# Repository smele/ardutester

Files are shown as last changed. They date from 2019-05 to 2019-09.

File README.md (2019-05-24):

# ardutester

#Work in progress...

An ATmega328 µC Component Tester based on work of ArduTester ver. 0.7f 

 Original Source from:        http://www.mikrocontroller.net/articles/AVR-Transistortester
 Original Software:           by Karl-Heinz Kuebbeler (kh_kuebbeler@web.de)
                              The Ardutester software is based on porting by Markus Reschke (madires@theca-tabellaria.de) 
 
 Schematic & Home Page:       
 
 Arduino version:             PighiXXX
                              PaoloP 
 
 - ONLY TTL COMPONENTS!

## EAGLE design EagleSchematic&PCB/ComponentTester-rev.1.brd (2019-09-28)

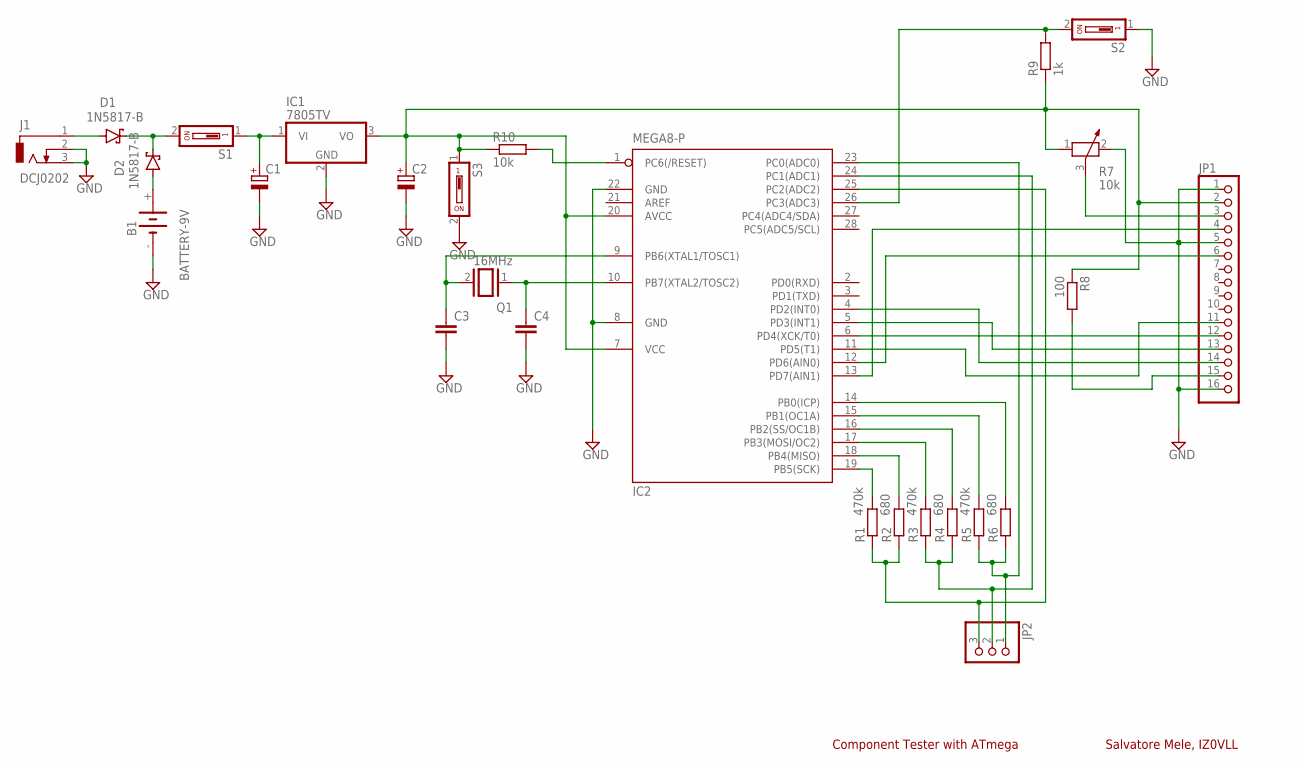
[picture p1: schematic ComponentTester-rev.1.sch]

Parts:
B1: BATTERY-9V; 9V-BATTERY-SNAP
C1, C2: CPOL-EUE2.5-6; E2,5-6
C3, C4: C-EU025-024X044; C025-024X044
D1, D2: 1N5817-B; DO41-7.6
IC1: 7805TV; TO220V
IC2: MEGA8-P; DIL28-3
J1: DCJ0202
JP1: PINHD-1X16; 1X16
JP2: PINHD-1X3; 1X03
Q1: 16MHz; QS
R1, R3, R5: 470k; 0207/10
R2, R4, R6: 680; 0207/10
R7: 10k; PT-10S
R8: 100; 0207/10
R9: 1k; 0207/10
R10: 10k; 0207/10
S1, S2, S3: SD4-01

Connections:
GND: B1.-, C1.-, C2.-, C3.2, C4.2, IC1.2 (GND), IC2.8 (GND), IC2.22 (GND), J1.2, J1.3, JP1.1, JP1.5, JP1.16, R7.2, S2.1, S3.2
unnamed: C1.+, IC1.1 (VI), S1.1
unnamed: C2.+, IC1.3 (VO), IC2.7 (VCC), IC2.20 (AVCC), JP1.2, R7.1, R8.1, R9.1, R10.1, S3.1
unnamed: IC2.14 (PB0(ICP)), R6.2
unnamed: IC2.15 (PB1(OC1A)), R5.2
unnamed: IC2.16 (PB2(SS/OC1B)), R4.2
unnamed: IC2.17 (PB3(MOSI/OC2)), R3.2
unnamed: IC2.18 (PB4(MISO)), R2.2
unnamed: IC2.19 (PB5(SCK)), R1.2
unnamed: IC2.25 (PC2(ADC2)), JP2.3, R1.1, R2.1
unnamed: IC2.24 (PC1(ADC1)), JP2.2, R3.1, R4.1
unnamed: IC2.23 (PC0(ADC0)), JP2.1, R5.1, R6.1
unnamed: JP1.3, R7.3
unnamed: IC2.26 (PC3(ADC3)), R9.2, S2.2
unnamed: IC2.13 (PD7(AIN1)), JP1.4
unnamed: IC2.12 (PD6(AIN0)), JP1.6
unnamed: IC2.4 (PD2(INT0)), JP1.14
unnamed: IC2.5 (PD3(INT1)), JP1.13
unnamed: IC2.6 (PD4(XCK/T0)), JP1.12
unnamed: IC2.11 (PD5(T1)), JP1.11
unnamed: JP1.15, R8.2
unnamed: C4.1, IC2.10 (PB7(XTAL2/TOSC2)), Q1.1
unnamed: C3.1, IC2.9 (PB6(XTAL1/TOSC1)), Q1.2
unnamed: IC2.1 (PC6(/RESET)), R10.2
unnamed: D1.A, J1.1
unnamed: B1.+, D2.A
unnamed: D1.C, D2.C, S1.2

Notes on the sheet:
Component Tester with ATmega
Salvatore Mele, IZ0VLL

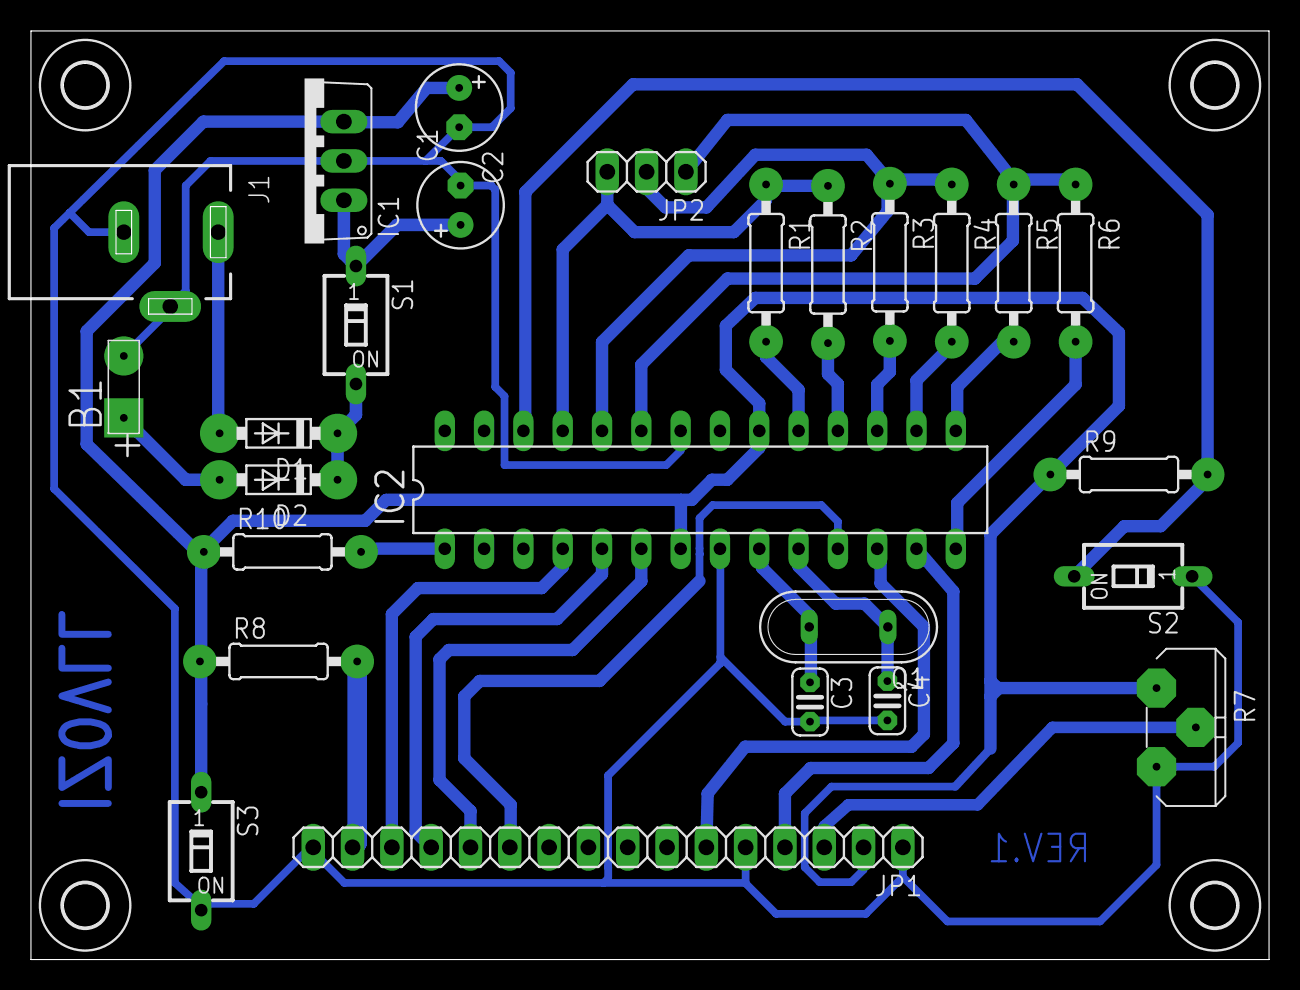
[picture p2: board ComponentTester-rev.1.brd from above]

Board: 2 copper layers, 80.0 x 60.0 mm, 30 parts (0 on the bottom side), 27 nets.

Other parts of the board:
U$1, U$2, U$3, U$4: 2,8

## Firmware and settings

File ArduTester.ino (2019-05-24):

/*

      ___           ___          _____          ___                       ___           ___                       ___           ___     
     /  /\         /  /\        /  /::\        /__/\          ___        /  /\         /  /\          ___        /  /\         /  /\    
    /  /::\       /  /::\      /  /:/\:\       \  \:\        /  /\      /  /:/_       /  /:/_        /  /\      /  /:/_       /  /::\   
   /  /:/\:\     /  /:/\:\    /  /:/  \:\       \  \:\      /  /:/     /  /:/ /\     /  /:/ /\      /  /:/     /  /:/ /\     /  /:/\:\  
  /  /:/~/::\   /  /:/~/:/   /__/:/ \__\:|  ___  \  \:\    /  /:/     /  /:/ /:/_   /  /:/ /::\    /  /:/     /  /:/ /:/_   /  /:/~/:/  
 /__/:/ /:/\:\ /__/:/ /:/___ \  \:\ /  /:/ /__/\  \__\:\  /  /::\    /__/:/ /:/ /\ /__/:/ /:/\:\  /  /::\    /__/:/ /:/ /\ /__/:/ /:/___
 \  \:\/:/__\/ \  \:\/:::::/  \  \:\  /:/  \  \:\ /  /:/ /__/:/\:\   \  \:\/:/ /:/ \  \:\/:/~/:/ /__/:/\:\   \  \:\/:/ /:/ \  \:\/:::::/
  \  \::/       \  \::/~~~~    \  \:\/:/    \  \:\  /:/  \__\/  \:\   \  \::/ /:/   \  \::/ /:/  \__\/  \:\   \  \::/ /:/   \  \::/~~~~ 
   \  \:\        \  \:\         \  \::/      \  \:\/:/        \  \:\   \  \:\/:/     \__\/ /:/        \  \:\   \  \:\/:/     \  \:\     
    \  \:\        \  \:\         \__\/        \  \::/          \__\/    \  \::/        /__/:/          \__\/    \  \::/       \  \:\    
     \__\/         \__\/                       \__\/                     \__\/         \__\/                     \__\/         \__\/    
		



 ARDUTESTER v0.X 25/04/2013
 
 Original Source from:        http://www.mikrocontroller.net/articles/AVR-Transistortester
 Original Software:           by Karl-Heinz Kuebbeler (kh_kuebbeler@web.de)
                              The Ardutester software is based on porting by Markus Reschke (madires@theca-tabellaria.de) 
 
 Schematic & Home Page:       http://www.pighixxx.com/lavori/ardutester/ 
 
 Arduino version:             PighiXXX (info@pighixxx.com)
                              PaoloP (http://www.arduino.cc/forum/index.php?action=profile;u=58300)
 
 - ONLY TTL COMPONENTS!
 
 TODO:
 - Detailed Component Analysis
 
 CHANGELOG:
 - 01/05/2013 v06e - Waitus Function, String to Flash Functions, Killed 3 Goto :-), Code Cleanup - PighiXXX 
 - 01/05/2013 v06f - Killed all Goto (Thanks to PaoloP), Implemented Button
 - 01/05/2013 v06g - Code Cleanup
 - 02/05/2013 v06h - Code Cleanup, SERIAL-LCD Flag, I2C LCD Functions
 - 02/05/2013 v06i - Button Flag, Button Function
 - 02/05/2013 v06j - PowerSave Function, Code Cleanup, Flag only when more info
 - 02/05/2013 v06k - Some fix (By PaoloP)
 - 03/05/2013 v06l - Disabled digital input on analog pins (By PaoloP), Minor fixes
 - 04/05/2013 v06m - ShowFET() fixed, Code Cleanup, Short Circuit Ok
 - 05/05/2013 v06n - CheckResistor Function Ok
 - 06/05/2013 v06o - SelfTest Function (v0.3), SelfAdjust, Minor fixes
 - 21/05/2013 v06p - Add LCD no I2C, Removed Leonardo support: this sketch work only on ATmega328. (By PaoloP)
 - 07/06/2013 v06q - ArduTester Software Client Functions (By PighiXXX)
 - 08/07/2013 v07a - SmallResistor() fixes, Inductance Measurement, Leakage Current Measurement, BJT functions fixed, Minor fixes (By PighiXXX)
                     TODO ReCheck Print Functions & LCD Functions - This is an alpha version! Lightless version!
 - 17/07/2013 v07b - MOSFETs function fixed, Minor fixes, Show Functions revisited, I2C LCD Deprecated, Deep debug :-)
                     Button Function revisited, PWM Tool, Serial Menu, AutoAdjust, EEProm functions (By PighiXXX)
 - 21/07/2013 v07c   Some fix (By PaoloP), LCD Functions revisited (By PighiXXX) 
 - 22/07/2013 v07d   LCDMenu, Some fix (By PighiXXX)
 - 23/07/2013 v07e   SetDefault function, Some fix, selFreq optimized, TestKey improvements, Client support (By PighiXXX)
                     TWI, SPI, TIMER2 disabled (By PaoloP)
 - 25/07/2013 v07f   ReadU function revisited (By PaoloP), Some fix (By PaoloP & PighiXXX)

*/

//WorkAround for IDE ifndef bug
char foo; 

                                                 //ARDUTESTER FEATURES

//Remember LCD_PRINT or DEBUG_PRINT
#define BUTTON_INST                              //Button Installed
#define LCD_PRINT                                //Print on LCD
//Remember DEBUG_PRINT or ATSW
//#define ATSW                                   //ArduTester Software Client Enabled
#define DEBUG_PRINT                            //Print on Serial Port
#define DET_COMP_ANALYSIS                        //Detailed Component Analysis (Soon)
#define TIMEOUT_BL            600                //LCD Backlight Timeout
#define LONG_PRESS            26                 //Button Long Press
#define USER_WAIT             3000               //Nexpage Timeout

//Check features
#if not defined(__AVR_ATmega328P__)
    #error Sorry, this program works only on Arduino Uno 
#endif
#if defined(LCD_PRINT) && defined(DEBUG_PRINT)
  #error Invalid Parameters: Use LCD_PRINT or DEBUG_PRINT
#endif

#if defined(DEBUG_PRINT) && defined(ATSW)
  #error Invalid Parameters: Use DEBUG_PRINT or ATSW
#endif

//Includes
#include <avr/wdt.h>
#include <avr/sleep.h>
#include <avr/power.h>
#include <EEPROM.h>

//LCD Output
#ifdef LCD_PRINT
  #include <LiquidCrystal.h>
  LiquidCrystal lcd(7, 6, 5, 4, 3, 2);           //RS,E,D4,D5,D6,D7
#endif

//UINT32_MAX
#define UINT32_MAX            ((uint32_t)-1)

//Test probes - Must be an ADC port :-)
#define ADC_PORT              PORTC              //ADC port data register 
#define ADC_DDR               DDRC               //ADC port data direction register 
#define ADC_PIN               PINC               //Port input pins register 
#define TP1                   0                  //Test pin 1 (=0) 
#define TP2                   1                  //Test pin 2 (=1) 
#define TP3                   2                  //Test pin 3 (=2) 
/*
   Probe resistors: 
   The resistors must be connected to the lower 6 pins of the port in
   following sequence:
    - pin 0: Rl1 680R (test pin 1)
    - pin 1: Rh1 470k (test pin 1)
    - pin 2: Rl2 680R (test pin 2)
    - pin 3: Rh2 470k (test pin 2)
    - pin 4: Rl3 680R (test pin 3)
    - pin 5: Rh3 470k (test pin 3)
*/
#define R_PORT                PORTB              //Port data register 
#define R_DDR                 DDRB               //Port data direction register

//Push button
#define TEST_BUTTON           A3                 //Test/start push button (low active)

//Button Delay
#define CYCLE_DELAY           3000

                                                 //ARDUESTER PARAMETERS

//Maximum number of measurements without any components found.
#define CYCLE_MAX             5
//ADC voltage reference based on Vcc (in mV). 
#define UREF_VCC              5001
/*
  Offset for the internal bandgap voltage reference (in mV): -100 up to 100
   - To compensate any difference between real value and measured value.
   - The ADC has a resolution of about 4.88mV for V_ref = 5V (Vcc) and
     1.07mV for V_ref = 1.1V (bandgap).
   - Will be added to measured voltage of bandgap reference.
*/
#define UREF_OFFSET           0
/*
   Exact values of probe resistors.
    - Standard value for Rl is 680 Ohms.
    - Standard value for Rh is 470k Ohms.
*/
//Rl in Ohms
#define R_LOW                 680
//Rh in Ohms
#define R_HIGH                470000
//Offset for systematic error of resistor measurement with Rh (470k) in Ohms.
#define RH_OFFSET             700 
/*
   Resistance of probe leads (in 0.01 Ohms).
    - Resistance of two probe leads in series.
    - Assuming all probe leads got same/similar resistance.
*/
#define R_ZERO                20
/* 
   Capacitance of the wires between PCB and terminals (in pF).
   Examples:
    - 2pF for wires 10cm long
*/
#define CAP_WIRES             15
/* 
   Capacitance of the probe leads connected to the tester (in pF).
   Examples:
     capacity  length of probe leads
     -------------------------------
      3pF      about 10cm
      9pF      about 30cm
     15pF      about 50cm
*/
#define CAP_PROBELEADS        9
//Maximum voltage at which we consider a capacitor being discharged (in mV)
#define CAP_DISCHARGED        2
/*
   Number of ADC samples to perform for each mesurement.
    - Valid values are in the range of 1 - 255.
*/
#define ADC_SAMPLES           25
//Estimated internal resistance of port to GND (in 0.1 Ohms)
#define R_MCU_LOW             200                //Default: 209
//Estimated internal resistance of port to VCC (in 0.1 Ohms)
#define R_MCU_HIGH            220                //Default: 235
//Voltage offset of ÂµCs analog comparator (in mV): -50 up to 50
#define COMPARATOR_OFFSET     15
//Capacitance of the probe tracks of the PCB and the ÂµC (in pF)
#define CAP_PCB               42
//Total default capacitance (in pF): max. 255
#define C_ZERO                CAP_PCB + CAP_WIRES + CAP_PROBELEADS
//ATMEGA328, 16Mhz Related
#define ADC_CLOCK_DIV         (1 << ADPS2) | (1 << ADPS1) | (1 << ADPS0)
#define CPU_FREQ              F_CPU
#define OSC_STARTUP           16384

//Components ID's
#define COMP_NONE             0
#define COMP_ERROR            1
#define COMP_MENU             2
#define COMP_RESISTOR         10
#define COMP_CAPACITOR        11
#define COMP_INDUCTOR         12
#define COMP_DIODE            20
#define COMP_BJT              21
#define COMP_FET              22
#define COMP_IGBT             23
#define COMP_TRIAC            24
#define COMP_THYRISTOR        25

//Chars
#define LCD_CHAR_UNSET        0                  //Just a place holder 
#define LCD_CHAR_DIODE1       1                  //Diode icon '>|' 
#define LCD_CHAR_DIODE2       2                  //Diode icon '|<' 
#define LCD_CHAR_CAP          3                  //Capacitor icon '||' 
#define LCD_CHAR_FLAG         4                  //Flag Icon
#define LCD_CHAR_RESIS1       6                  //Resistor left icon '[' 
#define LCD_CHAR_RESIS2       7                  //Resistor right icon ']'
#ifdef DEBUG_PRINT
  #define LCD_CHAR_OMEGA      79              
  #define LCD_CHAR_MICRO      '\u00B5'           //Code for Arduino Serial Monitor
#else
  #define LCD_CHAR_OMEGA      244                //Default: 244 
  #define LCD_CHAR_MICRO      228
#endif

//Error type IDs
#define TYPE_DISCHARGE        1                  //Discharge error

//FET type bit masks (also used for IGBTs)
#define TYPE_N_CHANNEL        0b00000001         //n channel 
#define TYPE_P_CHANNEL        0b00000010         //p channel 
#define TYPE_ENHANCEMENT      0b00000100         //Enhancement mode 
#define TYPE_DEPLETION        0b00001000         //Depletion mode 
#define TYPE_MOSFET           0b00010000         //MOSFET 
#define TYPE_JFET             0b00100000         //JFET 
#define TYPE_IGBT             0b01000000         //IGBT (no FET) 

//Mode bitmask
#define MODE_LOW_CURRENT      0b00000001         //Low test current 
#define MODE_HIGH_CURRENT     0b00000010         //High test current 
#define MODE_DELAYED_START    0b00000100         //Delayed start

//BJT (bipolar junction transistor) type IDs 
#define TYPE_NPN              1                  //NPN
#define TYPE_PNP              2                  //PNP

//Tester operation modes
#define MODE_CONTINOUS        0                  //Continous
#define MODE_AUTOHOLD         1                  //Auto hold 

//Multiplicator tables
#define TABLE_SMALL_CAP       1
#define TABLE_LARGE_CAP       2
#define TABLE_INDUCTOR        3

//Bit flags for PullProbe()
#define FLAG_PULLDOWN         0b00000000
#define FLAG_PULLUP           0b00000001
#define FLAG_1MS              0b00001000
#define FLAG_10MS             0b00010000

//Tester modes, offsets and values
typedef struct
{
  byte                        TesterMode;        //Tester operation mode
  byte                        SleepMode;         //MCU sleep mode 
  byte                        Samples;           //Number of ADC samples 
  byte                        AutoScale;         //Flag to disable/enable ADC auto scaling 
  byte                        RefFlag;           //Internal control flag for ADC 
  unsigned int                U_Bandgap;         //Voltage of internal bandgap reference (mV) 
  unsigned int                RiL;               //Internal pin resistance of ÂµC in low mode (0.1 Ohms) 
  unsigned int                RiH;               //Internal pin resistance of ÂµC in high mode (0.1 Ohms) 
  unsigned int                RZero;             //Resistance of probe leads (2 in series) (0.01 Ohms) 
  byte                        CapZero;           //Capacity zero offset (input + leads) (pF) 
  signed char                 RefOffset;         //Voltage offset of bandgap reference (mV) 
  signed char                 CompOffset;        //Voltage offset of analog comparator (mV) 
} Config_Type;

//Probes
typedef struct
{
  //Probe pins
  byte                        Pin_1;             //Probe-1
  byte                        Pin_2;             //Probe-2
  byte                        Pin_3;             //Probe-3 
  //Bit masks for switching probes and test resistors
  byte                        Rl_1;              //Rl mask for probe-1 
  byte                        Rh_1;              //Rh mask for probe-1 
  byte                        Rl_2;              //Rl mask for probe-2 
  byte                        Rh_2;              //Rh mask for probe-2 
  byte                        Rl_3;              //Rl mask for probe-3 
  byte                        Rh_3;              //Rh mask for probe-3 
  byte                        ADC_1;             //ADC mask for probe-1 
  byte                        ADC_2;             //ADC mask for probe-2 
} Probe_Type;

//Checking/probing
typedef struct
{
  byte                        Done;              //Flag for transistor detection done 
  byte                        Found;             //Component type which was found 
  byte                        Type;              //Component specific subtype 
  byte                        Resistors;         //Number of resistors found 
  byte                        Diodes;            //Number of diodes found 
  byte                        Probe;             //Error: probe pin 
  unsigned int                U;                 //Error: voltage left in mV 
} Check_Type;
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
void loop()
{
  byte Test;
  #ifdef BUTTON_INST
    Test = TestKey(0, 0);                        //Wait user
  #else
    delay(3000);                                 //No button installed, Wait 3 seconds
    Test=1;                                      //No button, no menu :-)
  #endif
  #ifdef WDT_enabled
    wdt_enable(WDTO_2S);                         //Enable watchdog (timeout 2s)
  #endif                 
  //Reset variables
  Check.Found = COMP_NONE;
  Check.Type = 0;
  Check.Done = 0;
  Check.Diodes = 0;
  Check.Resistors = 0;
  BJT.hFE = 0;
  BJT.I_CE0 = 0;
  //Reset hardware
  SetADCHiz();                                   //Set all pins of ADC port as input  
  lcd_clear();                                   //Clear LCD
  #ifdef LCD_PRINT 
    lcd_fixed_string(Splash_str);
    lcd_fixed_string(Version_str);
  #endif
  //Internal bandgap reference
  Config.U_Bandgap = ReadU(0x0e);                //Dummy read for bandgap stabilization 
  Config.Samples = 200;                          //Do a lot of samples for high accuracy 
  Config.U_Bandgap = ReadU(0x0e);                //Get voltage of bandgap reference 
  Config.Samples = ADC_SAMPLES;                  //Set samples back to default 
  Config.U_Bandgap += Config.RefOffset;          //Add voltage offset 
  if (Test==2)                                   //Long Press
  {
    wdt_disable();                               //Disable watchdog
    MainMenu();                                  //Main Menu
  }
  else
  {
    if (AllProbesShorted() == 3)                 //All probes Shorted!
      {
        #ifdef DEBUG_PRINT
          Serial.println();
        #endif
        lcd_fixed_string(Remove_str);            //Display: Remove/Create
        lcd_line(2);
        lcd_fixed_string(ShortCircuit_str);      //Display: short circuit! 
      }
      else
      {
        //Display start of probing
        lcd_line(2);                             //Move to line #2
        lcd_fixed_string(Running_str);           //Display: probing...
        DischargeProbes();
        if (Check.Found == COMP_ERROR)           //Discharge failed
        {                                        //Only for Standalone Version!                                     
          lcd_fixed_string(DischargeFailed_str); //Display: Battery?
          //Display probe number and remaining voltage
          lcd_line(2);
          lcd_testpin(Check.Probe);
          lcd_data(':');
          lcd_space();
          DisplayValue(Check.U, -3, 'V');
        }
        else                                     //Skip all other checks
        {
          //Check all 6 combinations of the 3 probes
          CheckProbes(TP1, TP2, TP3);
          CheckProbes(TP2, TP1, TP3);
          CheckProbes(TP1, TP3, TP2);
          CheckProbes(TP3, TP1, TP2);
          CheckProbes(TP2, TP3, TP1);
          CheckProbes(TP3, TP2, TP1);
          //If component might be a capacitor
          if ((Check.Found == COMP_NONE) ||
              (Check.Found == COMP_RESISTOR))
          {
            #ifdef DEBUG_PRINT
              Serial.println();
              Serial.println(X("Wait a moment..."));
            #else
              //Tell user to be patient with large caps
              lcd_clear_line(2);
              lcd_fixed_string(Running_str);
              lcd_data('.'); 
            #endif
            //Check all possible combinations
            MeasureCap(TP3, TP1, 0);
            #ifdef LCD_PRINT
              lcd_data('.'); 
            #endif
            MeasureCap(TP3, TP2, 1);
            #ifdef LCD_PRINT
              lcd_data('.'); 
            #endif
            MeasureCap(TP2, TP1, 2);
          }
          //Clear LCD
          lcd_clear();
          #ifdef BUTTON_INST
            pinMode(TEST_BUTTON, INPUT_PULLUP);  //Reinitialize the pushbutton pin as an input
          #endif          
          //Call output function based on component type
          #ifdef DEBUG_PRINT   
            Serial.print("Found: ");
            //Components ID's
            switch (Check.Found)
            {
              case COMP_ERROR:
                Serial.println(X("Component Error!"));
                break;
              case COMP_NONE:
                Serial.println(X("No Component!"));
                break;
              case COMP_RESISTOR:
                Serial.println(X("Resistor"));
                break;
              case COMP_CAPACITOR:
                Serial.println(X("Capacitor"));
                break;
              case COMP_INDUCTOR:
                Serial.println(X("Inductor"));
                break;
              case COMP_DIODE:
                Serial.println(X("Diode"));
                break;
              case COMP_BJT:
                Serial.println(X("BJT"));
                break;
              case COMP_FET:
                Serial.println(X("FET"));
                break;
              case COMP_IGBT:
                Serial.println(X("IGBT"));
                break;
              case COMP_TRIAC:
                Serial.println(X("TRIAC"));
                break;
              case COMP_THYRISTOR:
                Serial.println(X("Thyristor"));
                break;
            }
          #endif
          switch (Check.Found)
          {
            case COMP_ERROR:
              ShowError();
              break;
            case COMP_DIODE:
              ShowDiode();
              break;
            case COMP_BJT:
              ShowBJT();
              break;
            case COMP_FET:
              ShowFET();
              break;
            case COMP_IGBT:
              ShowIGBT();
              break;
            case COMP_THYRISTOR:
              ShowSpecial();
              break;
            case COMP_TRIAC:
              ShowSpecial();
              break;
            case COMP_RESISTOR:
              ShowResistor();
              break;
            case COMP_CAPACITOR:
              ShowCapacitor();
              break;
            default:                             //No component found
              ShowFail();
          }
          #ifdef ATSW                            //Client output
            Serial.println("@>");
            Serial.println(Check.Found);
            Serial.println("|");
            Serial.println(Check.Type);
            Serial.println("|");
            Serial.println(Check.Done);
            Serial.println("|");
            Serial.println("@<");
            //Component spedific output
          #endif
          //Component was found
          RunsMissed = 0;                        //Reset counter
          RunsPassed++;                          //Increase counter
        }
     }
  }  
  delay(1000);                                   //Let the user read the text
  wdt_disable();                                 //Disable watchdog
}

//Set ADC port to HiZ mode 
void SetADCHiz(void)
{
  ADC_DDR &= ~(1<<TP1);                                                           
  ADC_DDR &= ~(1<<TP2);
  ADC_DDR &= ~(1<<TP3);
}

//Set ADC port low
void SetADCLow(void)
{
  ADC_PORT &= ~(1<<TP1);                                                           
  ADC_PORT &= ~(1<<TP2);
  ADC_PORT &= ~(1<<TP3);
}

//Setup probes, bitmasks for probes and test resistors
void UpdateProbes(byte Probe1, byte Probe2, byte Probe3)
{
  //DSt probe IDs
  Probes.Pin_1 = Probe1;
  Probes.Pin_2 = Probe2;
  Probes.Pin_3 = Probe3;
  //Setup masks using bitmask tables
  Probes.Rl_1 = Rl_table[Probe1];
  Probes.Rh_1 = Probes.Rl_1 + Probes.Rl_1;
  Probes.ADC_1 = ADC_table[Probe1];
  Probes.Rl_2 = Rl_table[Probe2];
  Probes.Rh_2 = Probes.Rl_2 + Probes.Rl_2;
  Probes.ADC_2 = ADC_table[Probe2];
  Probes.Rl_3 = Rl_table[Probe3];
  Probes.Rh_3 = Probes.Rl_3 + Probes.Rl_3;
}
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
